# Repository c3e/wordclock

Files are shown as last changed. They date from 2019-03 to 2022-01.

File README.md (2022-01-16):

# Wordclock

Firmware für die WordClock (in der Art von https://www.amazon.de/dp/B01N5TKXP3/) vom c3e. Als Rahmen bietet sich ["RIBBA" von IKEA](https://www.ikea.com/de/de/catalog/products/40378401/) an.
Außerdem wird benötigt:
* Ein ESP8266 (z.B. [WeMos D1 Mini](https://www.amazon.de/dp/B076F53B6S/))
* Ein LED-Strip WS8212 mit 60 LED/m, 1m reicht (also 60 LED) z.B. von eBay
* Kabel in 3 Farben, am besten Draht, Litze 3-adrig flach geht notfalls auch
* Ein USB-Netzteil mit genügend Leistung z.B. https://www.amazon.de/dp/B00WLI5E3M
* Ein USB-Kabel
* Etwa 2.5 m² MDF (Mitteldichte Faserplatte) 2,5mm die gelasert wird
* Karton zum Lasern der Worte
* Viel Geduld beim Löten

## Hardware

Die MDF-Platte zuschneiden und mit den CAD-Dateien lasern (Makerspace in der Umgebung ansteuern, z.B. [Chaosdorf Düsseldorf](https://wiki.chaosdorf.de/Lasercutter), [Das Labor in Bochum](https://wiki.das-labor.org/w/LABOR_Wiki)). Die einzelnen LEDs vom Strip schneiden und auf die Trägerplatte an den vorgezeichneten Stellen aufkleben (z.B. mit UHU Flüssigkleber). Dabei darauf achten, dass die LEDs innerhalb einer Zeile immer die gleiche Ausrichtung (+5V, Din/DO, GND) haben und die Ausrichtungen von Zeile zu Zeile entgegengesetzt sind.
Die LEDs mit Drahtstücken verlöten, dabei darauf achten, dass alle Leitungen jeweils durchgängig verbunden sind (also alle +5V miteinander, alle GND, alle D) und nicht untereinander.
Am Anfang den ESP anlöten:
* 5V->+5V
* G->GND
* D1->Din (Pin-Benennung im Quelltext ist etwas anders)

### Material
* 230 mm x 230 mm Pappe (schwarz) für Wortfolie
  - -> [Wortfolie.dxf](cad-files/Wortfolie.dxf) verwenden
* 230 mm x 230 mm Transparentpapier (z.B. für technisches Zeichnen) als Diffusor, alternativ weißes Backpapier
* min 280 mm x 280 mm MDF für Trennwände
  - -> [Trennwaende_fuer_Laser.dxf](cad-files/Trennwaende_fuer_Laser.dxf) verwenden
  - Zahlen auf der linken Seite nach Möglichkeit nur gravieren oder weglassen
* Rückwand der Rahmens (CAD-Datei ist passend für "RIBBA" von IKEA)
  - -> [Rueckwand-ohne-Gravuren.dxf](cad-files/Rueckwand-ohne-Gravuren.dxf) (alle Konturen außer der Umrandung ganz ausschneiden) **oder**
  - -> [Rueckwand-mit-Gravuren.dxf](cad-files/Rueckwand-mit-Gravuren.dxf) (LED-Markierungen und Pfeile nur mit einer Tiefe von ca. 0.2-0.5 mm gravieren) verwenden

## Flashen
1. Dieses Repo clonen (`git clone https://github.com/c3e/wordclock.git`)
2. Die Arduino IDE installieren (https://www.arduino.cc/en/Main/Software)
3. Die Datei `wordclock/wordclock.ino` in der Arduino IDE öffnen
4. In der IDE unter Datei->Voreinstellungen->Zusätzliche Boardverwalter-URLs http://arduino.esp8266.com/stable/package_esp8266com_index.json hinzufügen
5. Unter Werkzeuge->Boards->Boardverwalter nach "esp" suchen, esp8266 installieren
6. Das richtige Board unter Werkzeuge->Boards aus wählen (z.B. WeMos D1 R1)
7. Sketcch->Bibliothek einbinden->Bibliotheken verwalten
8. Folgende installieren:
  * FastLED
  * WiFiManager
9. Folgende Zip-Dateien herunterladen:
  * https://github.com/PaulStoffregen/Time/archive/master.zip
  * https://github.com/JChristensen/Timezone/archive/master.zip
10. In der Arduino IDE unter Sketch->Bibliothek einbinden->.ZIP-Bibliothek hinzufügen die beiden heruntergeladenen .zip-Dateien auswählen
11. Den "Kompilieren"-Haken oben links anklicken (die Warnungen bzgl. Architektur und bitbanging können ignoriert werden)
12. Den ESP per USB anschließen
13. Den "Hochladen"-Pfeil klicken, darauf warten, dass der Upload vollständig ist (wird in Konsole und Statuszeile ausgegeben)

## Inbetriebnahme

1. Strom anschließen, 5V, USB-Netzeil
2. Ins WLAN `WordClock` verbinden (Der Name kann im Quelltext verändert werden)
3. Im Browser die IP `192.168.4.1` aufrufen
4. WLAN auswählen und ggf. Passwort eingeben
5. Nach dem Speichern der Einstellungen verschwindet das WLAN
6. Uhr zeigt die Uhrzeit an

Wenn das WLAN (wird für den Empfang der Uhrzeit benötigt) nicht mehr auffindbar ist, wird das Konfigurations-WLAN unter `192.168.4.1` automatisch wieder aufgebaut. Um die Einstellungen von Hand zurückzusetzen:
In der Arduino-IDE: Werkzeuge->Erase Flash->All Flash contents auswählen, dann den Programmcode erneut hochladen

## Design

Die Idee für das Design wurden vom FabLab Nürnberg übernommen. Die Firmware ist eine Eigenentwicklung.

http://wiki.fablab-nuernberg.de/w/Ding:Wortuhr_von_Udo

## Lizenz

MIT License

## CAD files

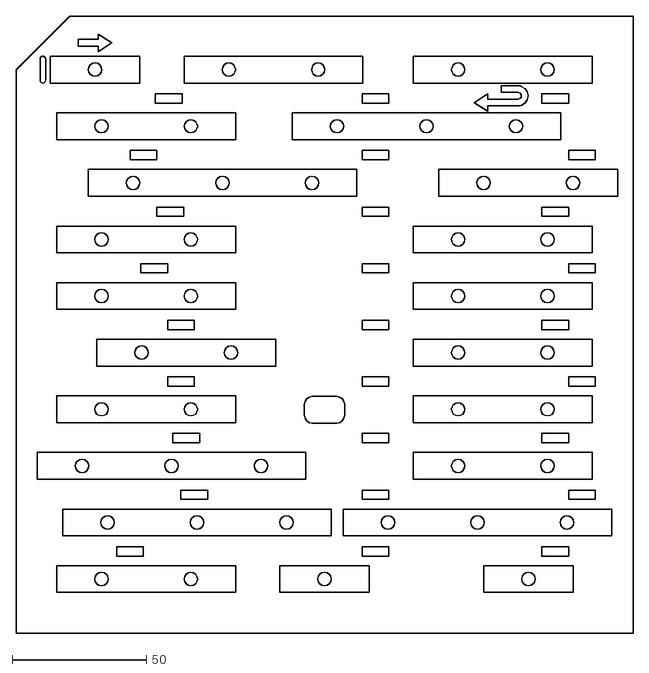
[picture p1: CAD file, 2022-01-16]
cad-files/Rueckwand-mit-Gravuren.dxf
230.0 x 230.0

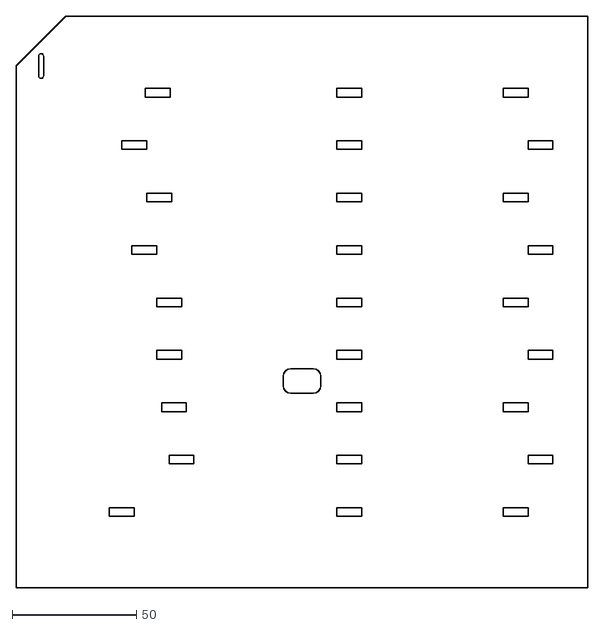
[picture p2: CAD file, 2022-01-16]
cad-files/Rueckwand-ohne-Gravuren.dxf
230.0 x 230.0

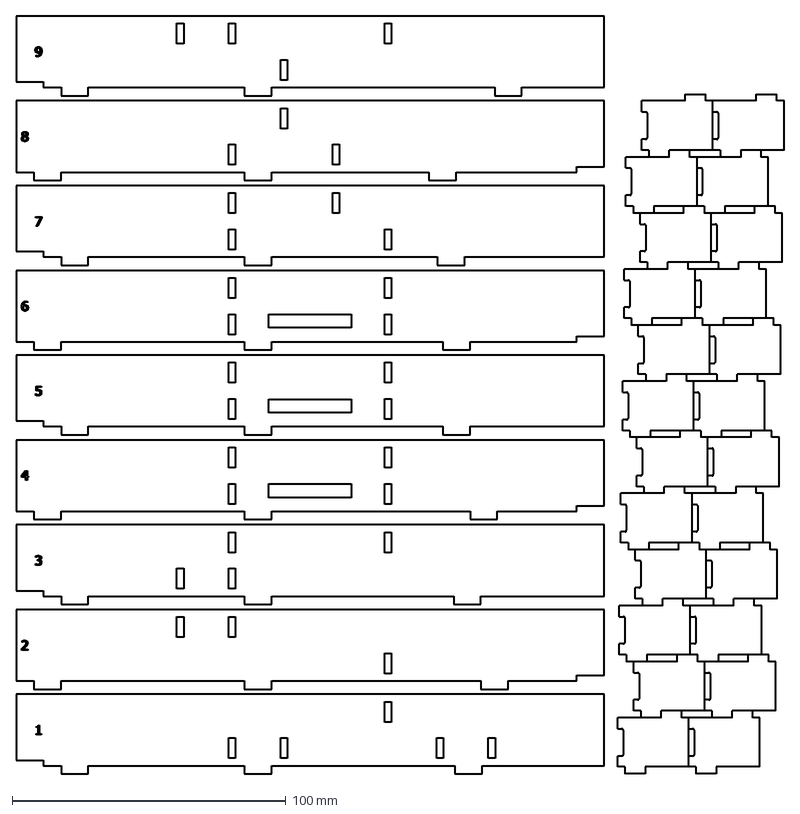
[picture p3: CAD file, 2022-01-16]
cad-files/Trennwaende_fuer_Laser.dxf
280.8 x 277.0 mm

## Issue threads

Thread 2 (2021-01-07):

CAD-Dateien zum Lasern der Schablonen fehlen

friesenkiwi, 2021-01-07:
Moin,

könnten die CAD-Dateien zum Lasern von Wort-Pappe und MDF-Stegen/Rückwand hier noch in das Repo hinzugefügt werden?

TheM4gici4N, 2022-01-16:
Probier mal aus, ob du mit den Daten im DXF-Format klar kommst. Wenn nicht, bitte noch mal das gewünschte Format nennen, dann exportiere ich dir das auch noch mal neu.

friesenkiwi, 2022-01-17:
Cool, vielen Dank! Das sollte funktionieren. Ich werde die Dateien ausprobieren, sobald die Pandemielage Zugriff auf einen Lasercutter erlaubt :-)

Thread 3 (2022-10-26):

Anderen auf anderes Front Layout

HoerMirAuf, 2022-10-26:
Hi.
ziemlich cooles Projekt. Ziemlich genau was ich suche.
Ich hab diese Worduhr bestellt:
[Bada-Bing - Amazone](https://www.amazon.de/Bada-Bing-Aufh%C3%A4ngen-Aufstellen-hochwertig/dp/B09N7C9G5D)
Und will das Innenleben auf WS3812 mit nem WEMOS umbauen.

Allerdings lassen sich dxf files nicht öffen um das Orginal Front-Layout einzusehe und dieses im ino File an mein Layout anzupassen.
Wäre es möglich das als PDF hochzuladen?

HoerMirAuf, 2022-10-28:
Ok, hat sich erledigt. Lag an einem Downloadfehler.
Allerdings scheinen die CAD Files nicht mit der INO übereinzustimmen, Anzahl der LEDS (bei manchen sind in der Übersicht 2 im Code nur eine)

Closed 2022-10-28.

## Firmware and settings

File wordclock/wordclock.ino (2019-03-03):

/**
 *  @file    wordclock.ino
 *  @author  telegnom (ccc@telegnom.org)
 *  @date    2019-02-23
 *  @version 1.1
 *
 *  @brief firmware for the c3e wordclock
 *
 *  requires the time.h and timezone.h libraries
 *  https://github.com/PaulStoffregen/Time/
 *  https://github.com/JChristensen/Timezone/
 *
 */


#include <FastLED.h>
#include <TimeLib.h>
#include <ESP8266WiFi.h>
#include <WiFiUdp.h>
#include <Timezone.h>
#include <DNSServer.h>
#include <ESP8266WebServer.h>
#include <WiFiManager.h>

#define BRIGHTNESS 200

#define NUM_LEDS 43
#define DATA_PIN 5

CRGB leds[NUM_LEDS];

// NTP Servers:
static const char ntpServerName[] = "pool.ntp.org";

// defining words

#define M_ES 0
#define M_IST 1
#define M_FUENF 2
#define M_ZEHN 3
#define M_ZWANZIG 4
#define M_VIERTEL 5
#define M_VOR 6
#define M_NACH 8
#define M_HALB 7
#define M_UHR 21
#define H_EINS 11
#define H_ZWEI 12
#define H_DREI 13
#define H_VIER 14
#define H_FUENF 10
#define H_SECHS 15
#define H_SIEBEN 17
#define H_ACHT 16
#define H_NEUN 9
#define H_ZEHN 19
#define H_ELF 20
#define H_ZWOELF 18

TimeChangeRule myDST = {"CEST", Last, Sun, Mar, 2, 120};    //Daylight time = UTC - 4 hours
TimeChangeRule mySTD = {"CET", Last, Sun, Oct, 2, 60};     //Standard time = UTC - 5 hours
Timezone myTZ(myDST, mySTD);

int clockWords[22][10] = {
  {0,-1,-1,-1,-1,-1,-1,-1,-1,-1}, // es 0
  {1,-1,-1,-1,-1,-1,-1,-1,-1,-1},  // ist 1
  {2,3,-1,-1,-1,-1,-1,-1,-1,-1},  // fuenf 2
  {7,8,-1,-1,-1,-1,-1,-1,-1,-1},  // zehn 3
  {4,5,6,-1,-1,-1,-1,-1,-1,-1}, //  zwanzig 4
  {9,10,11,-1,-1,-1,-1,-1,-1,-1},  // viertel 5
  {12,-1,-1,-1,-1,-1,-1,-1,-1,-1},  // vor 6
  {13,14,-1,-1,-1,-1,-1,-1,-1,-1},  // nach 8
  {15,16,-1,-1,-1,-1,-1,-1,-1,-1},  // halb 7
  {17,18,-1,-1,-1,-1,-1,-1,-1,-1},  // neun 9 
  {19,20,-1,-1,-1,-1,-1,-1,-1,-1},  // fuenf 10
  {23,24,-1,-1,-1,-1,-1,-1,-1,-1},  // eins 11
  {21,22,-1,-1,-1,-1,-1,-1,-1,-1},  // zwei 12
  {25,26,-1,-1,-1,-1,-1,-1,-1,-1},  // drei 13
  {27,28,-1,-1,-1,-1,-1,-1,-1,-1},  // vier 14
  {31,32,-1,-1,-1,-1,-1,-1,-1,-1},  // sechs 15
  {29,30,-1,-1,-1,-1,-1,-1,-1,-1},  // acht 16
  {33,34,35,-1,-1,-1,-1,-1,-1,-1},  // sieben 17
  {36,37,38,-1,-1,-1,-1,-1,-1,-1}, // zwölf 18
  {41,42,-1,-1,-1,-1,-1,-1,-1,-1},  // zehn 19
  {40,-1,-1,-1,-1,-1,-1,-1,-1,-1},  // elf 20
  {39,-1,-1,-1,-1,-1,-1,-1,-1},  // uhr 21
};

WiFiUDP Udp;
unsigned int localPort = 8888;  // local port to listen for UDP packets
time_t getNtpTime();
time_t loctime;
uint8_t color = 0;
int lastmin = 100;
void printDigits(int digits);
void sendNTPpacket(IPAddress &address);

void clear(bool show=true)
{
  for(int i = 0; i<NUM_LEDS;i++) {
    leds[i] = 0x000000;
  }
  if (show) {
    FastLED.show();
  }
}

void noWifi()
{
  for(int i=0; i<NUM_LEDS; i++)
  {
    leds[i] = CHSV((255/(NUM_LEDS-1))*i, 255, BRIGHTNESS);
    FastLED.show();
  }
}

void printDigits(uint8_t digits, bool colon = true)
{
  // utility for digital clock display: prints preceding colon and leading 0
  if (colon)
  {
    Serial.print(":");
  }
  if (digits < 10)
    Serial.print('0');
  Serial.print(digits);
}

void digitalClockDisplay()
{
  // digital clock display of the time
  printDigits((uint8_t) hour(loctime));
  printDigits((uint8_t) minute(loctime));
  printDigits((uint8_t) second(loctime));
  Serial.print(" ");
  Serial.print(day(loctime));
  Serial.print(".");
  Serial.print(month(loctime));
  Serial.print(".");
  Serial.print(year(loctime));
  Serial.println();
}

void setup()
{
  FastLED.addLeds<WS2812B, DATA_PIN, GRB>(leds, NUM_LEDS);
  clear();
  for (int initcount=0; initcount <= NUM_LEDS; initcount++) {
    clear();
    leds[initcount] = CHSV((255/NUM_LEDS)*initcount, 255, BRIGHTNESS);
    FastLED.show();
    delay(100);
  }
  clear();
  Serial.begin(115200);
  WiFiManager wifiManager;
  while (!Serial) ; // Needed for Leonardo only
  delay(250);
  Serial.println("WordClock by telegnom");
  Serial.print("Setup Wifi ... ");
  wifiManager.autoConnect("WordClock");
  Serial.println('[ ok ]');
  while (WiFi.status() != WL_CONNECTED) {
    noWifi();
    delay(500);
  }

  Serial.print("IP number assigned by DHCP is ");
  Serial.println(WiFi.localIP());
  Serial.println("Starting UDP");
  Udp.begin(localPort);
  Serial.print("Local port: ");
  Serial.println(Udp.localPort());
  Serial.println("waiting for sync");
  setSyncProvider(getNtpTime);
  setSyncInterval(600);
}

int prevDisplay = 100; // when the digital clock was displayed

void loop()
{
  // time_t utc = now();
  loctime = myTZ.toLocal(now());
  if (timeStatus() != timeNotSet) {
  //    if (prevDisplay != second(localtime))
    if (prevDisplay != second(loctime)) { //update the display only if time has changed
    prevDisplay = second(loctime);
      if (second()%10 == 0)
      {
        digitalClockDisplay();
        if (lastmin != minute(loctime))
        {
          setClock();
        }
        prevDisplay = second(loctime);
      }
  //  }
    }
  }
}

void set_word(int word, time_t current_time = loctime) {
  int wordlen = sizeof(clockWords[word])/sizeof(clockWords[word][0]);
  if (lastmin != minute(loctime))
  {
    color += 40;
  }
  for (int i=0; i<wordlen; i++)
  {
    if (clockWords[word][i] >= 0)
    {
      leds[clockWords[word][i]] = CHSV(color, 255, BRIGHTNESS);
      Serial.print(clockWords[word][i]);
      Serial.print("  ");
    }
  }
  Serial.println();
}

void setClock() {
  Serial.println("Updating display...");
  time_t current_time = loctime;
  clear(false);
  set_word(M_ES);  // switch es on
  set_word(M_IST);  // switch ist on
  getMinuteWord();  //get word for "minute"
  getHourWord();  // get word for hour
  FastLED.show(); //writing to led stipe
  lastmin = minute(loctime);
  Serial.println("... display updated.");
}

int getHour()
{
  int h = int(hour(loctime));
  int m = int(minute(loctime));
  /*
    get current hour if minute < 20
      Es ist viertel nach zehn
    get next hour if minute >=25
      Es ist fuenf vor halb elf
    adjust hour to correct word around midnight:
      23:25 --> Es ist fuenf vor halb zwoelf
  */
  Serial.println(m);
  if (m >= 25)
  {
    if (h < 23)
    {
      return h+1;
    } else
    {
      return 0;
    }
  } else
  {
    return h;
  }
}

void getHourWord()
{
  switch(getHour())
  {
    case 12:
    case 0:
      set_word(H_ZWOELF);
      Serial.println("zwoelf");
      break;
    case 1:
    case 13:
      // special case to get sigular @ "ein uhr"
      if (int(minute(loctime)) < 5)
      {
        set_word(H_EINS);
        Serial.println("ein");
      } else
      {
        set_word(H_EINS);
        Serial.println("eins");
      }
      break;
    case 2:
    case 14:
      set_word(H_ZWEI);
      Serial.println("zwei");
      break;
    case 3:
    case 15:
      set_word(H_DREI);
      Serial.println("drei");
      break;
    case 4:
    case 16:
      set_word(H_VIER);
      Serial.println("vier");
      break;
    case 5:
    case 17:
      set_word(H_FUENF);
      Serial.println("fuenf");
      break;
    case 6:
    case 18:
      set_word(H_SECHS);
      Serial.println("sechs");
      break;
    case 7:
    case 19:
      set_word(H_SIEBEN);
      Serial.println("sieben");
      break;
    case 8:
    case 20:
      set_word(H_ACHT);
      Serial.println("acht");
      break;
    case 9:
    case 21:
      set_word(H_NEUN);
      Serial.println("neun");
      break;
    case 10:
    case 22:
      set_word(H_ZEHN);
      Serial.println("zehn");
      break;
    case 11:
    case 23:
      set_word(H_ELF);
      Serial.println("elf");
      break;
  }
}

void getMinuteWord()
{
  /*
  get word for current "minute"
  */
  switch(int(minute(loctime)))
  {
    case 0:
    case 1:
    case 2:
    case 3:
    case 4:
      set_word(M_UHR);
      Serial.println("uhr");
      break;
    case 5:
    case 6:
    case 7:
    case 8:
    case 9:
      set_word(M_FUENF);
      set_word(M_NACH);
      Serial.println("fuenf nach");
      break;
    case 10:
    case 11:
    case 12:
    case 13:
    case 14:
      set_word(M_ZEHN);
      set_word(M_NACH);
      Serial.println("zehn nach");
      break;
    case 15:
    case 16:
    case 17:
    case 18:
    case 19:
      set_word(M_VIERTEL);
      set_word(M_NACH);
      Serial.println("viertel nach");
      break;
    case 20:
    case 21:
    case 22:
    case 23:
    case 24:
      set_word(M_ZWANZIG);
      set_word(M_NACH);
      Serial.println("zwanzig nach");
      break;
    case 25:
    case 26:
    case 27:
    case 28:
    case 29:
      set_word(M_FUENF);
      set_word(M_VOR);
      set_word(M_HALB);
      Serial.println("fuenf vor halb");
      break;
    case 30:
    case 31:
    case 32:
    case 33:
    case 34:
      set_word(M_HALB);
      Serial.println("halb");
      break;
    case 35:
    case 36:
    case 37:
    case 38:
    case 39:
      set_word(M_FUENF);
      set_word(M_NACH);
      set_word(M_HALB);
      Serial.println("fuenf nach halb");
      break;
    case 40:
    case 41:
    case 42:
    case 43:
    case 44:
      set_word(M_ZWANZIG);
      set_word(M_VOR);
      Serial.println("zehn nach halb");
      break;
    case 45:
    case 46:
    case 47:
    case 48:
    case 49:
      set_word(M_VIERTEL);
      set_word(M_VOR);
      Serial.println("viertel vor");
      break;
    case 50:
    case 51:
    case 52:
    case 53:
    case 54:
      set_word(M_ZEHN);
      set_word(M_VOR);
      Serial.println("zehn vor");
      break;
    case 55:
    case 56:
    case 57:
    case 58:
    case 59:
    case 60:
      set_word(M_FUENF);
      set_word(M_VOR);
      Serial.println("fuenf vor");
      break;
  }
}

/*-------- NTP code ----------*/

const int NTP_PACKET_SIZE = 48; // NTP time is in the first 48 bytes of message
byte packetBuffer[NTP_PACKET_SIZE]; //buffer to hold incoming & outgoing packets

time_t getNtpTime()
{
  IPAddress ntpServerIP; // NTP server's ip address

  while (Udp.parsePacket() > 0) ; // discard any previously received packets
  Serial.println("Transmit NTP Request");
  // get a random server from the pool
  WiFi.hostByName(ntpServerName, ntpServerIP);
  Serial.print(ntpServerName);
  Serial.print(": ");
  Serial.println(ntpServerIP);
  sendNTPpacket(ntpServerIP);
  uint32_t beginWait = millis();
  while (millis() - beginWait < 1500) {
    int size = Udp.parsePacket();
    if (size >= NTP_PACKET_SIZE) {
      Serial.println("Receive NTP Response");
      Udp.read(packetBuffer, NTP_PACKET_SIZE);  // read packet into the buffer
      unsigned long secsSince1900;
      // convert four bytes starting at location 40 to a long integer
      secsSince1900 =  (unsigned long)packetBuffer[40] << 24;
      secsSince1900 |= (unsigned long)packetBuffer[41] << 16;
      secsSince1900 |= (unsigned long)packetBuffer[42] << 8;
      secsSince1900 |= (unsigned long)packetBuffer[43];
      return secsSince1900 - 2208988800UL;
    }
  }
  Serial.println("No NTP Response :-(");
  return 0; // return 0 if unable to get the time
}

// send an NTP request to the time server at the given address
void sendNTPpacket(IPAddress &address)
{
  // set all bytes in the buffer to 0
  memset(packetBuffer, 0, NTP_PACKET_SIZE);
  packetBuffer[0] = 0b11100011;   // LI, Version, Mode
  packetBuffer[1] = 0;     // Stratum, or type of clock
  packetBuffer[2] = 6;     // Polling Interval
  packetBuffer[3] = 0xEC;  // Peer Clock Precision
  packetBuffer[12] = 49;
  packetBuffer[13] = 0x4E;
  packetBuffer[14] = 49;
  packetBuffer[15] = 52;
  Udp.beginPacket(address, 123); //NTP requests are to port 123
  Udp.write(packetBuffer, NTP_PACKET_SIZE);
  Udp.endPacket();
}

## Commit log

2019-02-23 Fix pin number
2019-02-23 test pattern added and words fixed
    [wordclock.ino]
2019-02-23 Fix small bugs (inverse pin numbers)
    [wordclock.ino]
2019-02-24 fix inverse lines
    partly again
    also fix "zehn vor halb"=>"zwanzig nach"
    [wordclock.ino]
2022-01-16 Add DXF files for lasercutting
    Updated description and added the files used to cut the wooden panels.
    [Rueckwand-mit-Gravuren.dxf, Rueckwand-ohne-Gravuren.dxf, Trennwaende_fuer_Laser.dxf]
2022-01-16 Use hyperlinks for cad-files
